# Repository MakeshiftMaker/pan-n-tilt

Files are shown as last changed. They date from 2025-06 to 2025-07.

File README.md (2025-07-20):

# Pan-Tilt System with Joystick Control :: ATMega328P

## Project Overview

This project implements a simple **pan-tilt mechanism** driven by two stepper motors, allowing manual control via a **2-axis analog joystick**. Users can adjust the **azimuth (pan)** and **elevation (tilt)** using joystick movements. A button on the joystick resets the system to its centered position. Additionally, orientation can be controlled via command-line input through a serial interface.

The system is built around an **ATmega32 microcontroller** and uses a custom hardware abstraction layer (**avrhal**) to manage stepper motors, ADC, USART communication, and joystick input.

---

## Features

- **Hardware-level control of stepper motors** using A4988 stepper drivers, managed through custom abstraction
- **Precise positioning** of the pan-tilt mechanism with an accuracy of 1° in both azimuth and elevation axes
- **Manual control** via a 2D analog joystick (X/Y axes) for intuitive real-time positioning
- **Position reset** function via joystick button to return to neutral (centered) orientation
- **USART interface** for remote control and feedback, compatible with EasyComm2-style commands
- **Interoperability with rotctl and Gpredict**, allowing for automatic satellite tracking
- **Low CPU overhead**, with motor stepping handled by hardware timers (no pin toggling in interrupts)
- **Command-line control** via serial terminal (e.g., `minicom`) to issue commands or monitor system status

---

## Hardware Setup

- **Microcontroller:** ATmega328P
- **Motor Control:** 2x stepper motors with A4988 drivers  
- **Joystick:** 2-axis analog joystick with integrated pushbutton  
- **Communication:** USART @ 9600 Baud, 8N1  
- **Custom HAL:** 
  - Stepper motor control
  - ADC input for joystick
  - USART serial communication

---

## Dependencies

- AVR Libc (`avr/io.h`)
- Custom AVR Hardware Abstraction Layer:
  - `avrhal/stepper.h`
  - `avrhal/joystick.h`
  - `avrhal/usart.h`
  - `avrhal/adc.h`
  - `avrhal/commandParser.h`
  - `utils/bit.h`

---

## Usage Instructions

### Manual Control (via Joystick)
1. **Move joystick left/right** – controls horizontal panning (azimuth)
2. **Move joystick up/down** – controls vertical tilting (elevation)
3. **Press joystick button** – resets both motors to their zero (center) position

### Remote Control (via USART)
Connect to the device using a serial terminal (e.g., `minicom`) at **9600 Baud, 8N1**. The following commands are supported:

#### Query Commands
- `STATUS`  
  Prints detailed stepper status and current angles in the format:  
  `P:<taken>/<remaining> T:<taken>/<remaining> p:<azimuth> t:<elevation>`
  
- `AZ`  
  Returns the current azimuth angle (in degrees):  
  `AZ<value>.0`

- `EL`  
  Returns the current elevation angle (in degrees):  
  `EL<value>.0`

#### Position Commands
- `AZ<value>`  
  Sets the azimuth to the specified angle (integer degrees).  
  Example: `AZ45`

- `EL<value>`  
  Sets the elevation to the specified angle.  
  Example: `EL30`

- `AZ<value> EL<value>`  
  Sets both azimuth and elevation in one command.  
  Example: `AZ90 EL45`

> **Note:** Commands are case-insensitive and must be followed by a newline (`\n`) or carriage return (`\r\n`) when sent over serial.

---

## TODO

- Implement **different microstepping modes** (currently only full-step is supported) for finer orientation control
- Refactor stepper logic to use **two independent hardware timers** for better per-motor speed control and increased flexibility
- Add **limit switch support** for physical range detection and homing
- Add EEPROM storage to **retain last known position** across power cycles
- Optional: Integrate **OLED or LCD** for local display of position or status

---

## Credits

- **CAD Model Design:**  
  Original pan-tilt CAD model by [Scienteer](https://www.youtube.com/watch?v=Su6O6155UJM)

- **FreeCAD Conversion:**  
  Converted to FreeCAD format by [Eyal Abraham](https://www.youtube.com/watch?v=LF1JT0Pmddc)

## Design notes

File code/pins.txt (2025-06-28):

PB0 -> Tilt Dir
PB1 -> Pan Dir
PB2 -> Tilt Enable
PB3 -> Pan Enable

all microstepping modes are grounded to full step mode

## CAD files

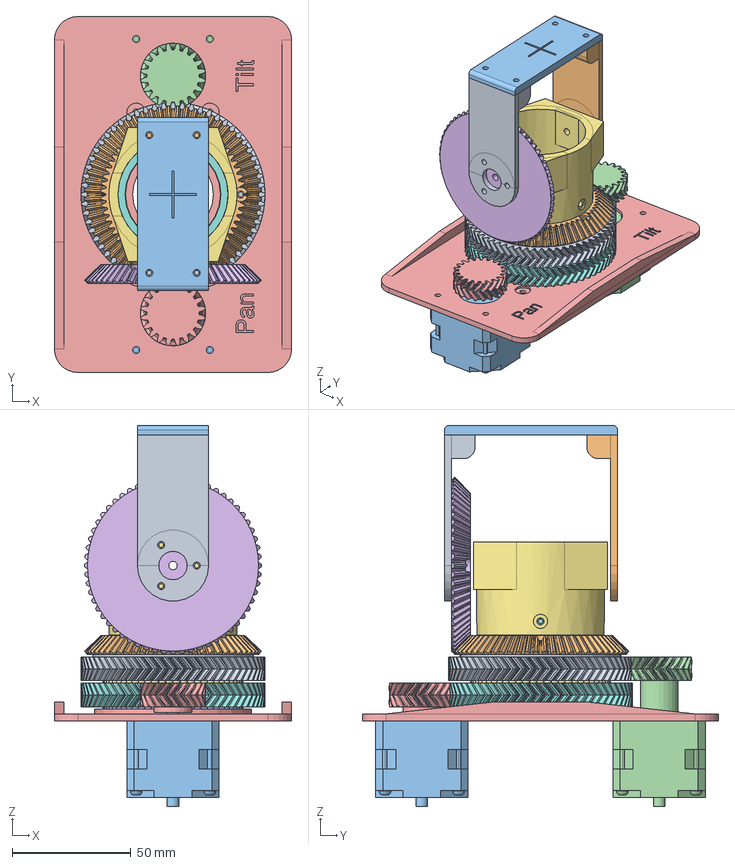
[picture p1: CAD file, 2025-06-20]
cad_models/differential-pan-tilt-1.snapshot.8/diff-pan-tilt-v2.FCStd
100.0 x 150.0 x 160.5 mm
tilt-arm
support-arm
payload-plate
tilt-pinion
pan-pinion
base-to-pan-bearings
pan-to-tilt-bearings
pan-base-gear
tilt-base-gear
bevel-gear001
pan-motor
tilt-motor
base-plate
bevel-gear002
turret

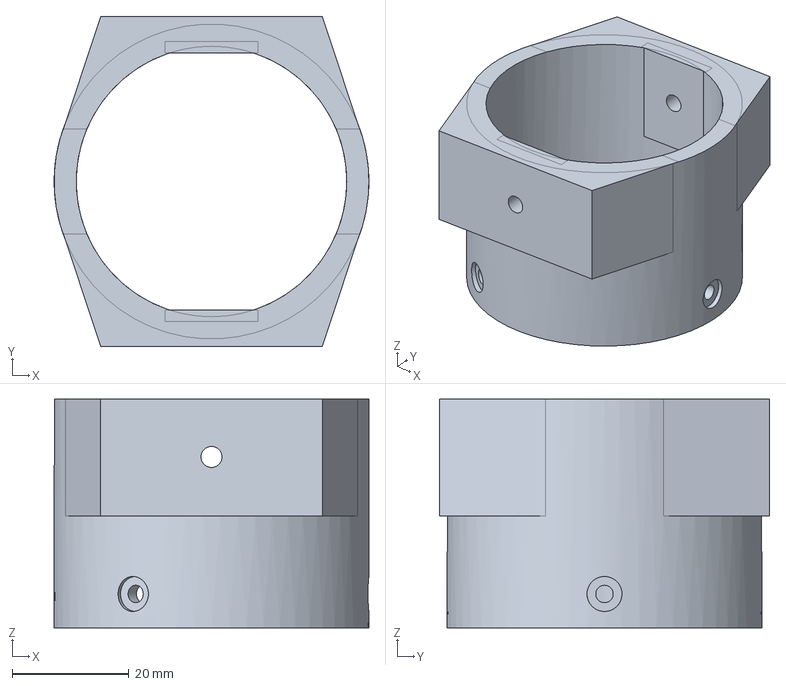
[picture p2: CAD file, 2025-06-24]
cad_models/turret.FCStd
54.0 x 56.6 x 39.2 mm

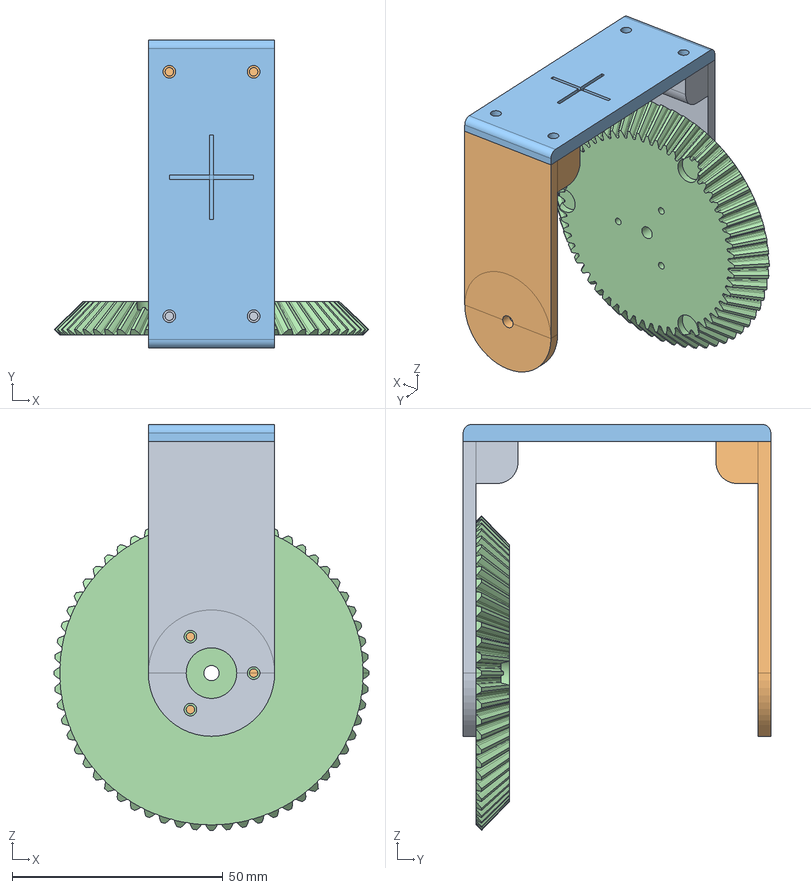
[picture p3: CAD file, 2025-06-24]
cad_models/tilt_arm.FCStd
74.7 x 73.0 x 96.3 mm
tilt-arm
support-arm
payload-plate
bevel-gear002

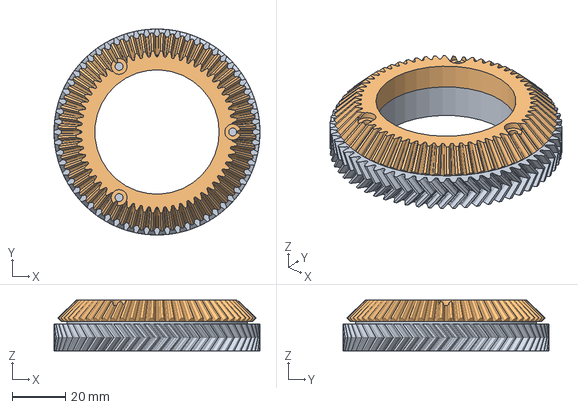
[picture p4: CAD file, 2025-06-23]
cad_models/tilt_base_and_bevel.FCStd
77.5 x 77.5 x 19.0 mm
tilt-base-gear
bevel-gear001

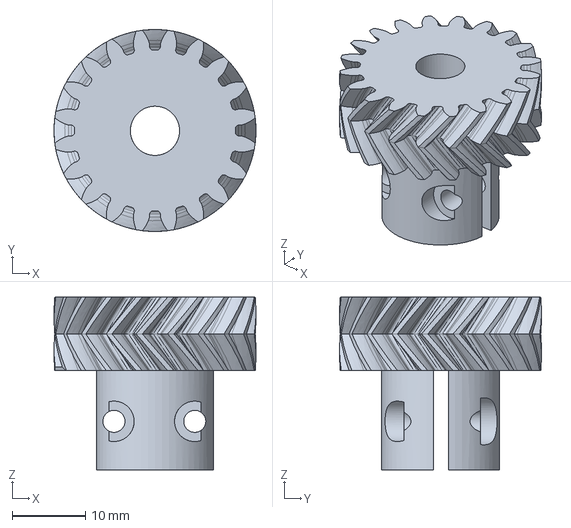
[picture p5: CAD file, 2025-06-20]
cad_models/tilt_pinion_new.FCStd
27.5 x 27.5 x 23.5 mm

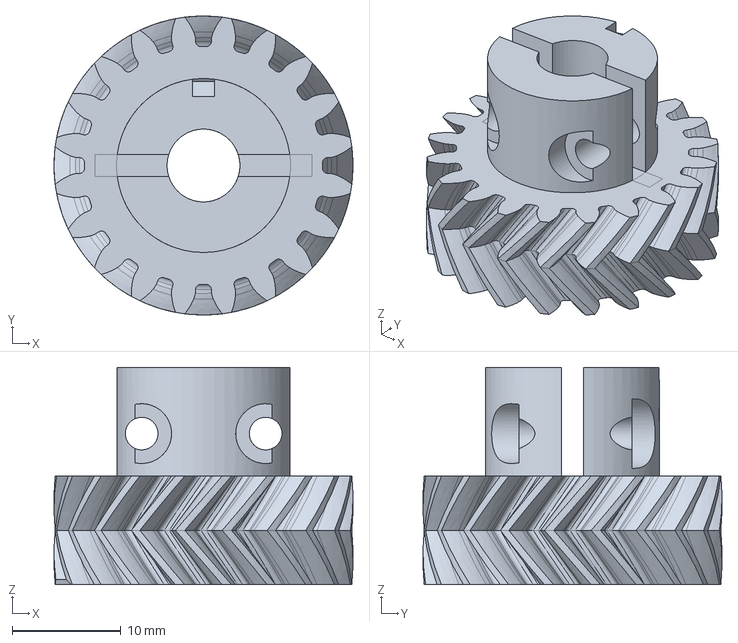
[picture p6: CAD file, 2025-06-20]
cad_models/pan_pinion_new.FCStd
27.5 x 27.5 x 20.0 mm

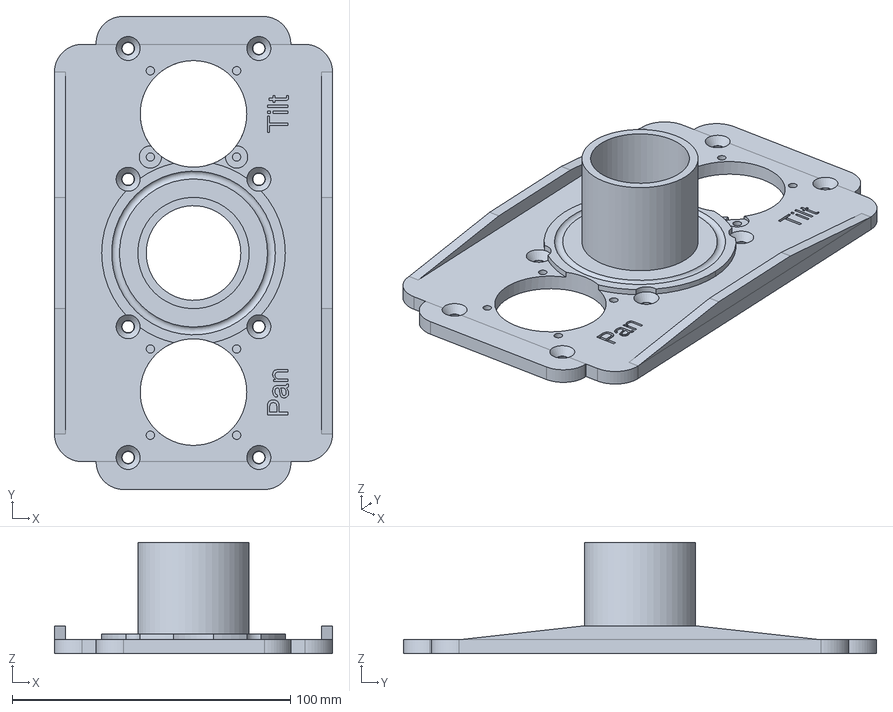
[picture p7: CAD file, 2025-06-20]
cad_models/stepper_base_plate.FCStd
100.0 x 170.0 x 40.0 mm

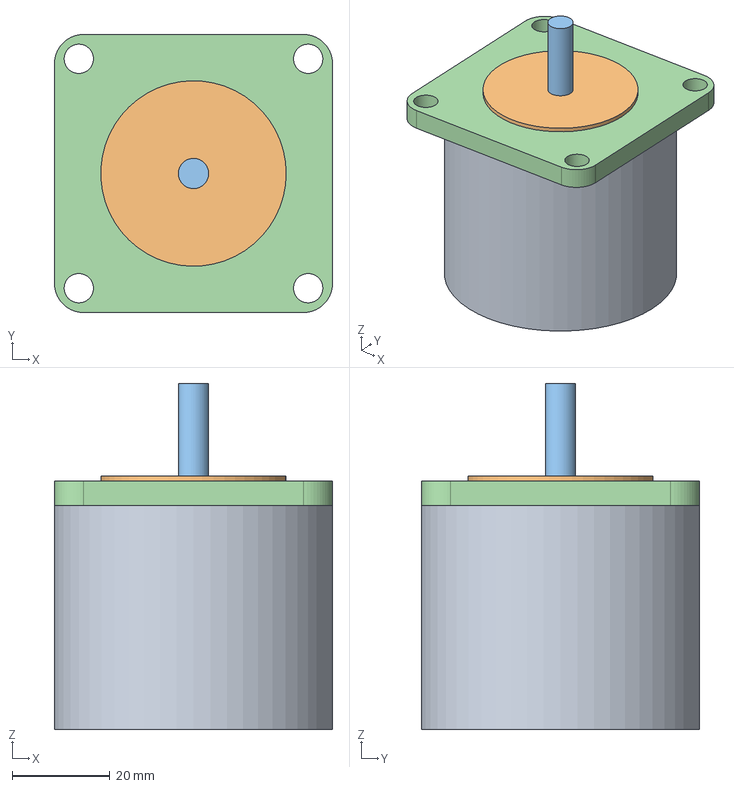
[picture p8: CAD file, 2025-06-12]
cad_models/stepper_motor.FCStd
57.0 x 57.0 x 70.9 mm
Motor_Body
Motor_Indent
Motor_Shaft
Motor_Bracket

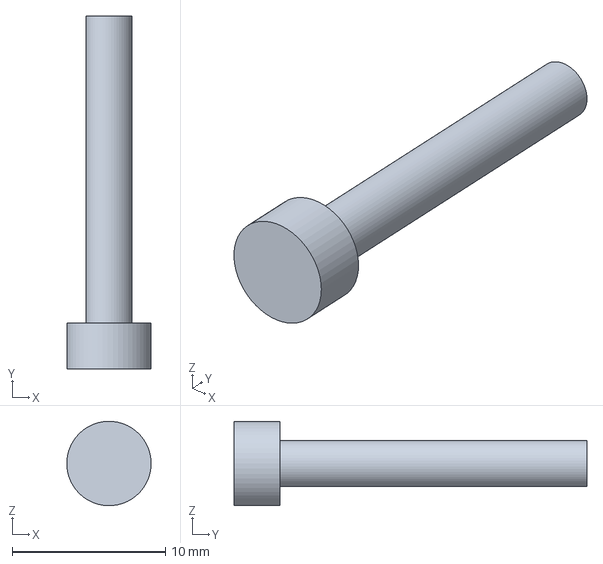
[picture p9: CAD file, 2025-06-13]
cad_models/m2_20mm.FCStd
5.49 x 23.0 x 5.50 mm

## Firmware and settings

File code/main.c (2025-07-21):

#include <avr/io.h>
#include <util/delay.h>
#include "avrhal/stepper.h"
#include "utils/bit.h"
#include "avrhal/joystick.h"
#include "avrhal/usart.h"
#include "avrhal/adc.h"
#include "utils/math.h"
#include "avrhal/commandParser.h"

#define PRESCALER TIMER_CLK_8
#define JOYSTICK_DEADZONE 50
#define MIN_FREQ 100
#define MAX_FREQ 150

Stepper stepper_tilt = {
    .ddr = &DDRD,
    .port = &PORTD,
    //.step_pin = PB6,
    .dir_pin = PD2,
    .en_pin = PD3,
    /*
    .ms1_pin = PB1,
    .ms2_pin = PB2,
    .ms3_pin = PB3,
    .rst_pin = PB4,
    .slp_pin = PB5,
    */
    .steps_taken = 0,
    .steps_remaining = 0,
    .step_pin_state = 0,

    .disable = false,
    .dir = false,
    //.microstep_mode = MICROSTEP_FULL,

    .config_dirty = false

};

Stepper stepper_pan = {
    .ddr = &DDRD,
    .port = &PORTD,
    //.step_pin = PD6,
    .dir_pin = PD4,
    .en_pin = PD6,
    /*
    .ms1_pin = PD1,
    .ms2_pin = PD2,
    .ms3_pin = PD3,
    .rst_pin = PD4,
    .slp_pin = PD5,
    */
    .steps_taken = 0,
    .steps_remaining = 0,
    .step_pin_state = 0,

    .disable = false,
    .dir = false,
    //.microstep_mode = MICROSTEP_FULL,

    .config_dirty = false};

int main(void)
{
    // enable interrupt
    sei();

    // joystick
    joystickSetup();
    int16_t joy[3];
    Direction direction = STOP;

    // steppers
    stepper_setup(&stepper_pan);
    stepper_setup(&stepper_tilt);
    stepper_heartbeat_setup();
    stepper_set_heartbeat(0, PRESCALER);
    stepper_heartbeat_set_clock_prescaler(PRESCALER);

    // int16_t max_offset;
    int freq = 0;
    int angles[4];

    // usart setup
    usartSetup(USART_B9600, USART_CONFIG_8N1);

    usartPrint("Setup: OK\n\rp-n-t V2.0.0\n\r");

    while (1)
    {
        stepper_get_angles(&stepper_pan, &stepper_tilt, angles);
        commandParserPoll(&stepper_pan, &stepper_tilt);

        //joystickRead(joy);
        //set to zero for now, since no joystick is attached
        int16_t x_offset = 0; //joy[0] - 510;
        int16_t y_offset = 0; //joy[1] - 495;

        direction = joystick_get_direction(x_offset, y_offset, JOYSTICK_DEADZONE);

        // if no joystick input
        if (direction == STOP)
        {
            freq = calculate_heartbeat_frequency(stepper_pan.steps_remaining, stepper_tilt.steps_remaining, MIN_FREQ, MAX_FREQ);
        }
        else
        {
            int16_t max_offset = absInt16(x_offset) > absInt16(y_offset) ? absInt16(x_offset) : absInt16(y_offset);

            // Map offset (0–500ish) to heartbeat frequency (50–150 Hz)
            freq = 50 + (max_offset * 100) / 500;
            if (freq > 150)
                freq = 150;
        }

        stepper_set_heartbeat(freq, PRESCALER);

        if (stepper_tilt.steps_remaining == 0 && stepper_pan.steps_remaining == 0)
        {
            switch (direction)
            {
            case LEFT:
                stepper_step_n(&stepper_pan, 1, 1);
                stepper_step_n(&stepper_tilt, 1, 1);
                break;
            case RIGHT:
                stepper_step_n(&stepper_pan, 1, 0);
                stepper_step_n(&stepper_tilt, 1, 0);
                break;
            case DOWN:
                stepper_step_n(&stepper_tilt, 1, 0);
                break;
            case UP:
                stepper_step_n(&stepper_tilt, 1, 1);
                break;
            case STOP:
                break;
            }
        }

        static int prev_button = 0;
        if (joy[2] == 1 && prev_button == 0)
        {
            stepper_goto_position(&stepper_pan, &stepper_tilt, 0, 90);
        }
        prev_button = joy[2];

        // usartPrint("PD0 (RXD): %d, PD1 (TXD): %d\r\n", pd0_val, pd1_val);
        // usartPrint("test\r\n");

        // usartPrint("Joystick X: %+d, Y: %+d\r\n", joy[0] - 510, joy[1] - 495);
        //usartPrint("Joystick X: %+d, Y: %+d, Freq: %d Hz\r\n", x_offset, y_offset, freq);

        /*
        static int tmp_counter = 0;
        tmp_counter++;
        if (tmp_counter > 500)
        {
            const char *dir_str[] = {"S", "L", "R", "U", "D"};
            usartPrint("D:%s P:%ld/%d T:%ld/%d p:%d t:%d f:%d\r\n",
                       dir_str[direction],
                       stepper_pan.steps_taken, stepper_pan.steps_remaining,
                       stepper_tilt.steps_taken, stepper_tilt.steps_remaining,
                       angles[0], angles[2], freq);
            tmp_counter = 0;
        }
        */
    }

    return 0;
}

ISR(TIMER1_COMPA_vect)
{
    static uint8_t phase = 0;
    phase ^= 1;
    if (phase == 1)
        return; // count only full pulse (2 edges = 1 pulse)

    // --- PAN STEPPER ---
    if (stepper_pan.steps_remaining > 0)
    {
        if (stepper_pan.disable)
        { // enable only if currently disabled
            stepper_set_disable(&stepper_pan, false);
            stepper_apply_config(&stepper_pan);
        }
        stepper_pan.steps_remaining--;
        stepper_pan.steps_taken += (stepper_pan.dir) ? -1 : 1;
    }
    else
    {
        if (!stepper_pan.disable)
        { // disable only if currently enabled
            stepper_set_disable(&stepper_pan, true);
            stepper_apply_config(&stepper_pan);
        }
    }

    // --- TILT STEPPER ---
    if (stepper_tilt.steps_remaining > 0)
    {
        if (stepper_tilt.disable)
        {
            stepper_set_disable(&stepper_tilt, false);
            stepper_apply_config(&stepper_tilt);
        }

        stepper_tilt.steps_remaining--;
        stepper_tilt.steps_taken += (stepper_tilt.dir) ? -1 : 1;
    }
    else
    {
        if (!stepper_tilt.disable)
        {
            stepper_set_disable(&stepper_tilt, true);
            stepper_apply_config(&stepper_tilt);
        }
    }
}

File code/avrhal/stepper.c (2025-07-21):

#include "stepper.h"
#include "../utils/bit.h"
// #include <util/delay.h>
#include <avr/interrupt.h>
#include <stdint.h>
#include <stdlib.h>
#include "usart.h"

#define FCLK 16000000UL

#define GEAR_RATIO 3   // motor steps are 3x gear output
#define STEP_ANGLE 1.8 // degrees per full motor step
#define FULL_ROTATION 360
#define TILT_MIN 0
#define TILT_MAX 90

#define PRESCALER 8


void stepper_setup(Stepper *s)
{
    // Set direction of control pins as output
    // BIT_SET(*(s->ddr), s->step_pin);
    BIT_SET(*(s->ddr), s->dir_pin);
    BIT_SET(*(s->ddr), s->en_pin);
    /*
    BIT_SET(*(s->ddr), s->ms1_pin);
    BIT_SET(*(s->ddr), s->ms2_pin);
    BIT_SET(*(s->ddr), s->ms3_pin);
    BIT_SET(*(s->ddr), s->rst_pin);
    BIT_SET(*(s->ddr), s->slp_pin);
    */

    // Set STEP and DIR low
    /*
    BIT_CLR(*(s->port), s->step_pin);
    BIT_CLR(*(s->port), s->dir_pin);

    // Set RST and SLP high
    BIT_SET(*(s->port), s->rst_pin);
    BIT_SET(*(s->port), s->slp_pin);
    */

    // Set EN (active-low) high = disable driver
    // default disabled
    BIT_SET(*(s->port), s->en_pin);

    // Clear microstep mode bits (full step mode)
    /*
    BIT_CLR(*(s->port), s->ms1_pin);
    BIT_CLR(*(s->port), s->ms2_pin);
    BIT_CLR(*(s->port), s->ms3_pin);
    */

    //_delay_us(5000);
}


void stepper_heartbeat_setup()
{ // set up timer1 to interrupt with frequency f Hz
    // set up the TCCR1A/B registries

    BIT_SET(DDRB, PB1);
    BIT_SET(DDRB, PB2);

    // clear compare output for pb1 (normal operation) but set pb2 to toggle on compare match
    BIT_CLR(TCCR1A, COM1A1);
    BIT_CLR(TCCR1A, COM1A0);
    BIT_CLR(TCCR1A, COM1B1);
    BIT_SET(TCCR1A, COM1B0);
    // clear force output compare as per datasheet
    BIT_CLR(TCCR1A, FOC1A);
    BIT_CLR(TCCR1A, FOC1B);
    // set WGM in TCCR1A/B to use CTC compare mode
    BIT_CLR(TCCR1A, WGM10);
    BIT_CLR(TCCR1A, WGM11);
    BIT_SET(TCCR1B, WGM12);
    BIT_CLR(TCCR1B, WGM13);
    // disable Input Capture noise canceler and clear Input Capture Edge Select
    BIT_CLR(TCCR1B, ICNC1);
    BIT_CLR(TCCR1B, ICES1);
    // set Clock Select bits to use prescaler 8, 8MHZ/8 is 1MHZ = 1us per tick
    // clock is disabled on setup, use heartbeat_enable to start
    /*
    BIT_CLR(TCCR1B, CS12);
    BIT_SET(TCCR1B, CS11);
    BIT_CLR(TCCR1B, CS10);
    */
    // enable interrupts on compare match
    BIT_SET(TIMSK1, OCIE1A);

}

uint16_t get_prescaler_value(TimerPrescaler prescaler) {
    switch (prescaler) {
        case TIMER_CLK_NO_PRESCALE: return 1;
        case TIMER_CLK_8:           return 8;
        case TIMER_CLK_64:          return 64;
        case TIMER_CLK_256:         return 256;
        case TIMER_CLK_1024:        return 1024;
        default:                    return 0; // 0 for NO_CLOCK or external sources
    }
}

void stepper_set_heartbeat(int f, TimerPrescaler prescaler)
{
    OCR1A = (FCLK / (2 * get_prescaler_value(prescaler) * f)) - 1;
}


void stepper_heartbeat_set_clock_prescaler(TimerPrescaler prescaler)
{
    /*
    // Set prescaler to 8: CS12 = 0, CS11 = 1, CS10 = 0
    BIT_CLR(TCCR1B, CS12);
    BIT_SET(TCCR1B, CS11);
    BIT_CLR(TCCR1B, CS10);
    */

    //query each bit in the prescaler enum and set bits accordingly
    BIT_ASSIGN(TCCR1B, CS12, (prescaler & 0b100));
    BIT_ASSIGN(TCCR1B, CS11, (prescaler & 0b010));
    BIT_ASSIGN(TCCR1B, CS10, (prescaler & 0b001));
}

// helper functions
void stepper_set_disable(Stepper *s, bool disable)
{
    s->disable = disable;
    s->config_dirty = true;
}

void stepper_set_dir(Stepper *s, bool dir)
{
    s->dir = dir;
    s->config_dirty = true;
}

void stepper_set_microstep(Stepper *s, MicrostepMode mode)
{
    s->microstep_mode = mode;
    s->config_dirty = true;
}

void stepper_apply_config(Stepper *s)
{
    if (!s->config_dirty)
        return;

    // Update ENABLE pin (active-low)
    BIT_ASSIGN(*(s->port), s->en_pin, s->disable);

    // Update direction
    BIT_ASSIGN(*(s->port), s->dir_pin, s->dir);

    // Update microstepping mode
    /*
    BIT_CLR(*(s->port), s->ms1_pin);
    BIT_CLR(*(s->port), s->ms2_pin);
    BIT_CLR(*(s->port), s->ms3_pin);

    BIT_ASSIGN(*(s->port), s->ms1_pin, (s->microstep_mode & 0b100));
    BIT_ASSIGN(*(s->port), s->ms2_pin, (s->microstep_mode & 0b010));
    BIT_ASSIGN(*(s->port), s->ms3_pin, (s->microstep_mode & 0b001));
    */

    s->config_dirty = false;
}

bool stepper_is_dirty(Stepper *s)
{
    return s->config_dirty;
}

void stepper_step_n(Stepper *stepper, int steps, bool dir)
{
    stepper_set_dir(stepper, dir);
    stepper_apply_config(stepper);
    stepper->steps_remaining += steps;
}

uint8_t stepper_microstep_multiplier(MicrostepMode mode)
{
    switch (mode)
    {
    case MICROSTEP_FULL:
        return 16;
    case MICROSTEP_HALF:
        return 8;
    case MICROSTEP_QUARTER:
        return 4;
    case MICROSTEP_EIGHTH:
        return 2;
    case MICROSTEP_SIXTEENTH:
        return 1;
    default:
        return 16; // fallback to full steps
    }
}

void stepper_reset_position(Stepper *stepper)
{
    int32_t steps = stepper->steps_taken;

    if (steps == 0)
        return;

    bool direction = steps > 0 ? 0 : 1; // Reverse direction
    int32_t abs_steps = steps > 0 ? steps : -steps;

    stepper_step_n(stepper, abs_steps, direction);
    // stepper_set_heartbeat(100);
    // stepper->steps_taken = 0;  // Reset to zero here to avoid re-triggering
}

// angles[0] = pan_whole (0..359)
// angles[1] = pan_frac (0..99)
// angles[2] = tilt_whole (0..359)
// angles[3] = tilt_frac (0..99)

void stepper_get_angles(const Stepper *pan, const Stepper *tilt, int angles[4])
{
    int32_t motor_pan_deg_x100 = pan->steps_taken * 180; // steps * 1.8 * 100
    int32_t motor_tilt_deg_x100 = tilt->steps_taken * 180;

    int32_t pan_deg_x100 = motor_pan_deg_x100 / 3;
    pan_deg_x100 %= 36000;
    if (pan_deg_x100 < 0)
        pan_deg_x100 += 36000;

    int32_t tilt_deg_x100 = (motor_tilt_deg_x100 - motor_pan_deg_x100) / 3 + 9000;
    tilt_deg_x100 %= 36000;
    if (tilt_deg_x100 < 0)
        tilt_deg_x100 += 36000;

    angles[0] = pan_deg_x100 / 100;
    angles[1] = pan_deg_x100 % 100;
    angles[2] = tilt_deg_x100 / 100;
    angles[3] = tilt_deg_x100 % 100;
}

// Helper: convert degrees to motor steps (full steps)
static int deg_to_steps(int deg)
{
    return (int)((deg * GEAR_RATIO) / STEP_ANGLE);
}

// Helper: shortest signed difference between two angles 0..359
static int shortest_angle_diff(int current, int target)
{
    int diff = target - current;
    if (diff > 180)
        diff -= 360;
    else if (diff < -180)
        diff += 360;
    return diff;
}
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

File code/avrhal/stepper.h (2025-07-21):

#ifndef STEPPER_H
#define STEPPER_H

#include <avr/io.h>
#include <stdbool.h>
#include <avr/interrupt.h>

typedef enum
{
    MICROSTEP_FULL = 0b000,
    MICROSTEP_HALF = 0b100,
    MICROSTEP_QUARTER = 0b010,
    MICROSTEP_EIGHTH = 0b110,
    MICROSTEP_SIXTEENTH = 0b111
} MicrostepMode;


typedef enum {
    TIMER_NO_CLOCK        = 0x00, // 000: No clock source (Timer/Counter stopped)
    TIMER_CLK_NO_PRESCALE = 0x01, // 001: clk I/O (no prescaling)
    TIMER_CLK_8           = 0x02, // 010: clk I/O /8
    TIMER_CLK_64          = 0x03, // 011: clk I/O /64
    TIMER_CLK_256         = 0x04, // 100: clk I/O /256
    TIMER_CLK_1024        = 0x05, // 101: clk I/O /1024
    TIMER_EXT_FALLING     = 0x06, // 110: External clock source on T0 pin, falling edge
    TIMER_EXT_RISING      = 0x07  // 111: External clock source on T0 pin, rising edge
} TimerPrescaler;


typedef struct
{
    volatile uint8_t *ddr;
    volatile uint8_t *port;
    //const uint8_t step_pin;
    const uint8_t dir_pin;
    const uint8_t en_pin;
    /*
    const uint8_t ms1_pin;
    const uint8_t ms2_pin;
    const uint8_t ms3_pin;
    const uint8_t rst_pin;
    const uint8_t slp_pin;
    */

    volatile int32_t steps_taken; //in 1/16 steps
    volatile uint16_t steps_remaining;
    volatile bool step_pin_state;

    // Configuration shadow state
    volatile bool disable; // Desired state of enable pin (false = enable motor)
    volatile bool dir;     // Desired direction
    volatile MicrostepMode microstep_mode;

    // Internal tracking
    volatile bool config_dirty; // Dirty flag to apply config safely
} Stepper;

// Initialization and configuration
void stepper_setup(Stepper *s);
void stepper_apply_config(Stepper *s);

// Configuration setters
void stepper_set_disable(Stepper *s, bool disable);
void stepper_set_dir(Stepper *s, bool dir);
void stepper_set_microstep(Stepper *s, MicrostepMode mode);

bool stepper_is_dirty(Stepper* s);
uint8_t stepper_microstep_multiplier(MicrostepMode mode);

// Heartbeat timer control
void stepper_heartbeat_setup();
void stepper_set_heartbeat(int f, TimerPrescaler prescaler);
void stepper_heartbeat_set_clock_prescaler(TimerPrescaler prescaler);

//stepper control
void stepper_step_n(Stepper* stepper, int steps, bool dir);
void stepper_reset_position(Stepper* stepper);
void stepper_goto_position(Stepper* pan, Stepper* tilt, int target_pan_deg, int target_tilt_deg);

//getter
void stepper_get_angles(const Stepper* pan, const Stepper* tilt, int angles[4]);
int calculate_heartbeat_frequency(uint16_t pan_steps, uint16_t tilt_steps, uint8_t min_freq, uint8_t max_freq);
uint16_t get_prescaler_value(TimerPrescaler prescaler);


#endif

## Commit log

2025-06-13 modeled m2 20mm screw
    [m2_20mm.FCStd]
2025-06-13 datasheet for stepper motor
2025-06-19 updated tolerances
    [stepper_base_plate.FCStd]
2025-06-20 renamed stepper.h to stepper.c
2025-06-20 increased shaft diameter of pan and tilt pinion
    [pan_pinion_new.FCStd, tilt_pinion_new.FCStd]
2025-06-20 testing multi-stepper support
2025-06-22 Added Interrupt based stepping and easier ways to interface with the motor drivers
2025-06-22 added stepper_step_n() function to precisely(-ish) step any amount of desired steps
2025-06-23 added stepper counter
2025-06-23 increased drill hole size in the tilt gears
    [tilt_base_and_bevel.FCStd]
2025-06-23 got main.c from stepper test codes
2025-06-24 final cad parts
    [tilt_arm.FCStd, turret.FCStd]
2025-06-24 joystick und step ausgabe
2025-06-24 added reset position on button press
    [main.c, stepper.c]
2025-06-24 updated stepper homing logic
2025-06-24 switched pan and tilt
2025-06-26 troubleshooting slower stepper...
2025-06-26 fixed overflow error causing undefined stepper behaviour in usart.c
    [main.c]
2025-06-29 added safeguard to make sure goto command is finished before issueing the next one
    [stepper.c]
2025-07-01 reduced max speed in auto-mode to reduce missed steps
    [main.c]
2025-07-21 divided sterpper_setup and stepper_set_heartbeat more clearly to avoid code-replication
    [main.c, stepper.c, stepper.h]
2025-07-21 renamed stepper_heartbeat_enable to stepper_heartbeat_set_clock_prescaler for clarity, removed stepper_heartbeat_disable since that is included in set_prescaler
